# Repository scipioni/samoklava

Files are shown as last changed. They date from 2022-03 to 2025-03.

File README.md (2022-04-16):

# samoklava
## An autogenerated split 36 key keyboard

left | right
-|-
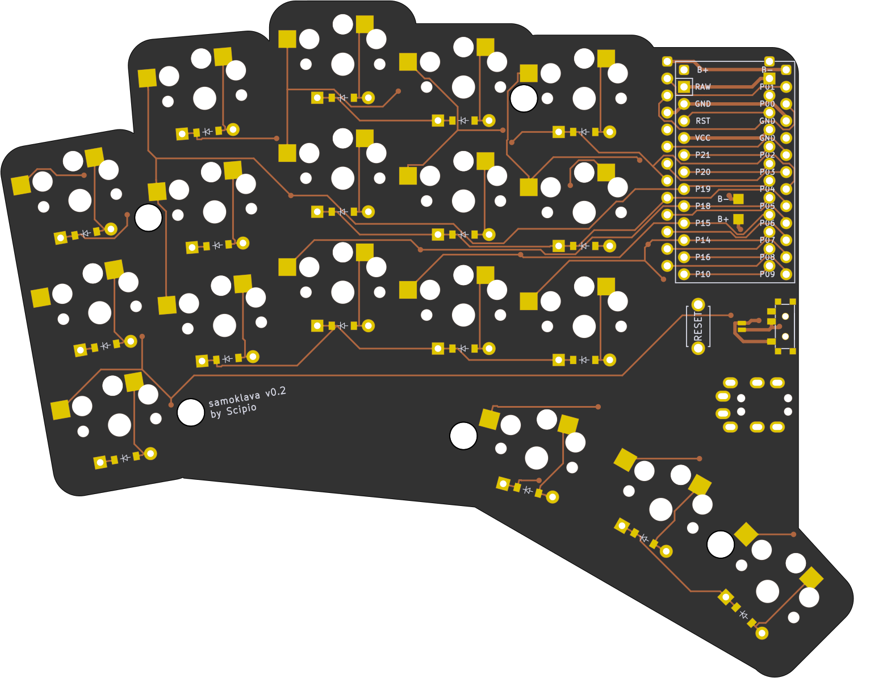
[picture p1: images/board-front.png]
left
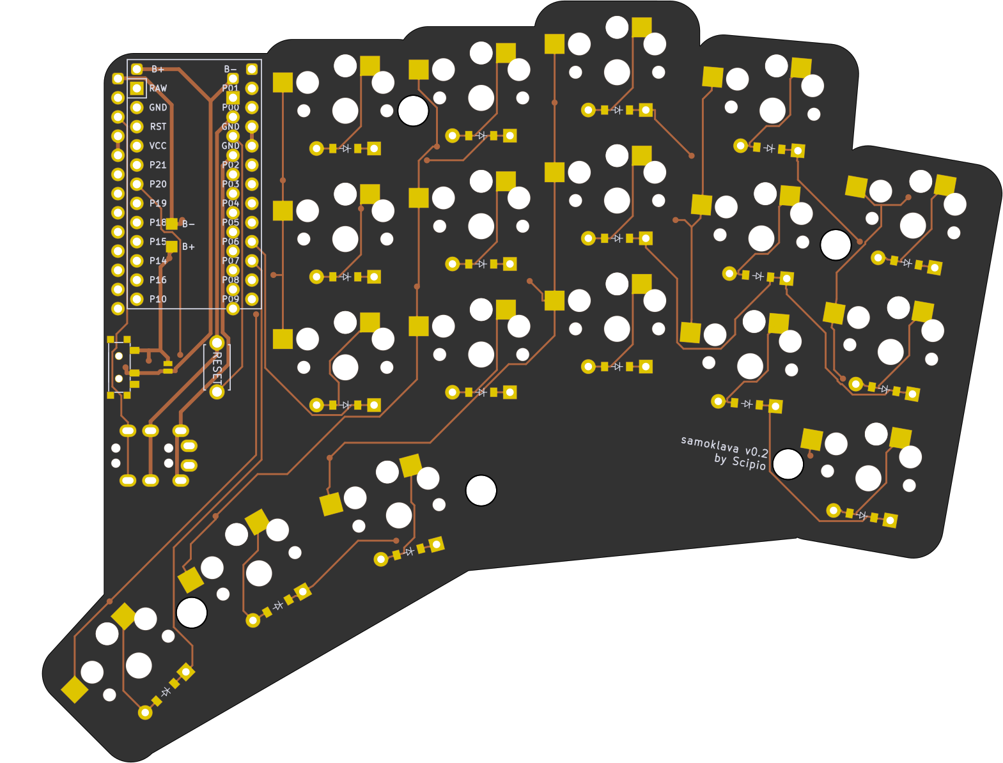
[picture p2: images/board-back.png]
right
 | 

A 5x3 split keyboard with 3 thumbs. There is nothing unique about the keyboard layout. It's inspired by Corne and Kyria, and
has the exact number of keys needed for the [Miryoku](https://github.com/manna-harbour/miryoku) layout.

The interesting thing about this keyboard is that it's a declarative design ("samoklava" can be loosely translated as
"keyboard that assembles itself" from Russian).
* Layout is declared using [Ergogen](https://github.com/mrzealot/ergogen/)
* The build system uses Ergogen to translate YAML to a KiCad PCB and plate files for FR-4 fab or laser cutting
* uses [kicad-automation-scripts](https://github.com/productize/kicad-automation-scripts) and [FreeRouting](https://github.com/freerouting/freerouting) to **automatically route the traces on the PCB**
* uses [KiKit](https://github.com/yaqwsx/KiKit) to render PCB previews (see top of this file) and production-ready **Gerber files**

## Features

* Extra pins and a slider switch for battery for wireless Promicro clones (tested with nice!nano); the slider can be
  shorted with a jumper if `CONFIG_ZMK_SLEEP` is preferred.
* Wired operation with QMK should be possible but is not tested; TRRS footprints are included and routed. The pinout is
  identical with a five-column Corne sans the RGBLEDs.
* Reset switches are easily accessible. The footprints used are the same as on the Corne.

## How to

  * make sure to have Docker CLI and NodeJS installed
  * run `make setup clean all`
  * check the `output` folder for KiCad PCBs and Gerbers
  * optional: create png render with `make png` and check output/routed_pcbs/board-front.png

See the [workflow](.github/workflows/build.yml) or the [Makefile](Makefile) for more details.

## Test layout

* https://ergogen.cache.works/

Upload samoklava.json except pcbs section. I print on paper with dxf format on qcad and:
* edit sheet properties -> printer offset -60,-60  

## Convert output dxf to svg

```
https://convertio.co/
```

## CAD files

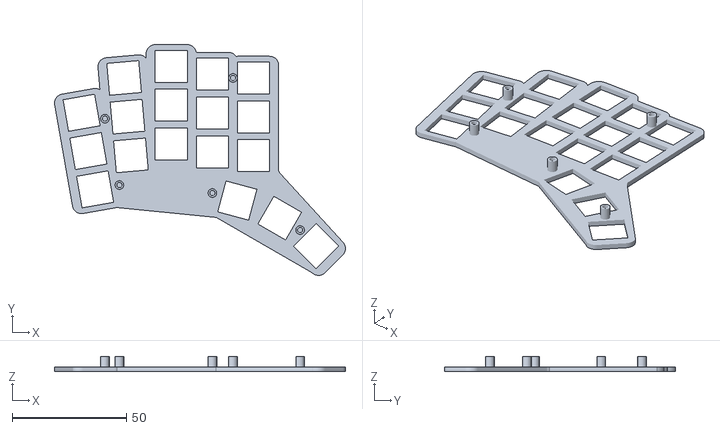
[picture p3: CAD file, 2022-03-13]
3d/samoklava.stl
127.3 x 100.9 x 6.55

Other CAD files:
3d/samoklava.blend

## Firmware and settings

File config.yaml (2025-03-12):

meta:
  engine: 4.0.4
  name: samoklava
  version: 0.3
  author: soundmonster
  url: https://github.com/soundmonster/samoklava
units:
  kx: cx
  ky: cy
  px: 2
  py: 2
points:
  key:
    footprints:
      choc_hotswap:
        type: choc
        params:
          hotswap: true
          reverse: true
          keycaps: true
        nets:
          from: =colrow
          to: =column_net
      diode:
        type: diode
        nets:
          from: =colrow
          to: =row_net
        anchor:
          shift: [0, -5]
  zones:
    matrix:
      key.padding: ky
      columns:
        pinky:
          key:
            stagger: 0 ky
            spread: kx
            column_net: col_pinky
        ring:
          key:
            stagger: 0.7 ky
            spread: kx
            column_net: col_ring
        middle:
          key:
            stagger: 0.2 ky
            spread: kx
            column_net: col_middle
        index:
          key:
            stagger: -0.2 ky
            spread: kx
            column_net: col_index
        inner:
          key:
            stagger: -0.1 ky
            spread: kx
            column_net: col_inner
      rows:
        bottom:
          row_net: row_bottom
        home:
          row_net: row_home
        top:
          row_net: row_top
    thumbfan:
      anchor:
        ref: matrix_inner_bottom
        shift: [-0.5 kx, -1 ky]
      columns:
        near:
          key:
            spread: kx
            splay: -15
            origin: [-0.5 kx, -0.5 ky]
            column_net: col_middle
        home:
          key:
            spread: kx
            splay: -15
            origin: [-0.5 kx, -0.5 ky]
            column_net: col_index
        far:
          key:
            spread: kx
            splay: -15
            origin: [-0.5 kx, -0.5 ky]
            column_net: col_inner
      rows:
        thumb:
          row_net: row_thumb
outlines:
  # board dimensions according to JLCPCB: 122.28 mm x 101.05 mm
  raw:
    - what: rectangle
      where: true
      asym: source
      size: [kx + px, ky + py]
      corner: px
  thumbfan_glue:
    - what: polygon
      points:
        - ref: matrix_inner_bottom
          shift: [0.5 kx + 0.5px, -0.5 ky + 0.5 py]
        - ref: thumbfan_far_thumb
          shift: [0.5 kx - 0.5px, 0.5 ky + 0.5 py]
        - ref: thumbfan_far_thumb
          shift: [0.5 kx - 0.5px, -0.5 ky - 0.5 py]
        - ref: thumbfan_near_thumb
          shift: [-0.5 kx + 0.5 px, -0.5 ky - 0.5 py]
        - ref: matrix_pinky_bottom
          shift: [0.5 kx - 0.5 py, -0.5 ky - 0.5 py]
        - ref: matrix_pinky_home
        - ref: matrix_inner_home
  patch_outer:
    - what: polygon
      points:
        - ref: matrix_ring_top
        - ref: matrix_ring_bottom
        - ref: matrix_pinky_bottom
          shift: [-0.5 (kx + px), 0]
        - ref: matrix_pinky_top
          shift: [-0.5 (kx + px), 0]
  patch_inner:
    - what: polygon
      points:
        - ref: matrix_inner_top
          shift: [0.5 (kx + px), 0]
        - ref: matrix_inner_bottom
          shift: [0.5 (kx + px), 0]
        - ref: matrix_index_bottom
        - ref: matrix_index_top
  controller_area:
    - what: rectangle
      where:
        - ref: matrix_inner_top
          # re-tranalte to new anchor position
          shift: [32/2 + 0 kx, 76.5/2 - 4.05 ky]
      size: [32, 76.5]
      corner: px
  switches:
    - what: rectangle
      where: true
      asym: source
      size: 14
  keycaps:
    - what: rectangle 
      where: true
      asym: source
      size: [kx, ky] 
      corner: 1
  keywell:
    - "raw"
    - "+patch_inner"
    - "+patch_outer"
    - "+thumbfan_glue"
  base_outline:
    - "keywell"
    - "+controller_area"
  screw_holes:
    top_left:
      what: circle
      where:
        - ref: matrix_ring_home
          shift: [-0.5 kx, 0 ky]
      radius: 1.05
    bottom_left:
      what: circle
      where:
        - ref: matrix_pinky_bottom
          shift: [0.5 kx, 0]
      radius: 1.05
    top_right:
      what: circle
      where:
        - ref: matrix_inner_top
          shift: [-0.5 kx, 0]
      radius: 1.05
    palm:
      what: circle
      where:
        - ref: matrix_index_bottom
          shift: [0, -1.06 ky]
      radius: 1.05
    thumb:
      what: circle
      where:
        - ref: thumbfan_far_thumb
          shift: [-0.55 kx, 0]
      radius: 1.05
  mounting_holes:
    $extends: outlines.screw_holes
    top_left:
      radius: 2.05
    bottom_left:
      radius: 2.05
    top_right:
      radius: 2.05
    palm:
      radius: 2.05
    thumb:
      radius: 2.05
  bottom_outline:
    - "base_outline"
    # TODO use footprints with pad + via reinforcement as mounting holes
    - "-screw_holes"
  plate:
    - "keywell"
    - "-switches"
    - "-screw_holes"
  pcb:
    - "base_outline"
    # TODO use footprints with pad + via reinforcement as mounting holes
    - "-mounting_holes"
pcbs:
  top_plate:
    outlines:
      edge:
        outline: plate
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

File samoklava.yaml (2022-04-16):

units:
  kx: cx
  ky: cy
  px: 4
  py: 2
points:
  key:
    footprints:
      choc_hotswap:
        type: choc
        params:
          hotswap: true
          reverse: true
          keycaps: true
        nets:
          # from: P1
          # to: P2
          from: =colrow
          to: =column_net
      diode:
        type: diode
        nets:
          # from: P3
          # to: P4
          from: =colrow
          to: =row_net
        anchor:
          shift: [0, -5]
  zones:
    matrix:
      # anchor:
      #   rotate: 5
      key.padding: 1 ky 
      columns:
        pinky:
          stagger: 0 ky
          spread: kx
          rotate: 12
          key:
            column_net: P20
        ring:
          stagger: 0.7 ky
          spread: kx
          rotate: -7
          key:
            column_net: P19
        middle:
          stagger: 0.2 ky
          spread: kx
          rotate: -5
          key:
            column_net: P18
        index:
          stagger: -0.2 ky
          spread: kx
          rotate: -0
          key:
            column_net: P15
        inner:
          stagger: -0.1 ky
          spread: kx
          key:
            column_net: P14
      rows:
        bottom:
          row_net: P6
        home:
          row_net: P5
        top:
          row_net: P4
    thumbfan:
      anchor:
        ref: matrix_inner_bottom
        shift: [-1.5 kx, -1.0 ky]
      columns:
        near:
          spread: kx
          rotate: -15
          origin: [-0.5 kx, -0.5 ky]
          key:
            column_net: P18
        home:
          spread: kx
          rotate: -15
          origin: [-0.5 kx, -0.5 ky]
          key:
            column_net: P15
        far:
          spread: kx
          rotate: -15
          origin: [-0.5 kx, -0.5 ky]
          key:
            column_net: P14
      rows:
        thumb:
          row_net: P7
outlines:
  # board dimensions according to JLCPCB: 122.28 mm x 101.05 mm
  exports:
    raw:
      - type: keys
        side: left
        size: [kx + px, ky + py]
        corner: px
    thumbfan_glue:
      - type: polygon
        points:
          - ref: matrix_inner_bottom
            shift: [0.5 kx + 0.6px, -0.5 ky + 0.5 py]
          - ref: thumbfan_far_thumb
            shift: [0.5 kx - 0.5px, 0.5 ky + 0.5 py]
          - ref: thumbfan_far_thumb
            shift: [0.5 kx - 0.5px, -0.5 ky - 0.5 py]
          - ref: thumbfan_near_thumb
            shift: [-0.5 kx + 0.5 px, -0.5 ky - 0.5 py]
          - ref: matrix_pinky_bottom
            shift: [0.5 kx - 0.5 py, -0.5 ky - 0.5 py]
          - ref: matrix_pinky_home
          - ref: matrix_inner_home
    patch_outer:
      - type: polygon
        points:
          - ref: matrix_ring_top
          - ref: matrix_ring_bottom
          - ref: matrix_pinky_bottom
            shift: [-0.5 (kx + px), 0]
          - ref: matrix_pinky_top
            shift: [-0.5 (kx + px), 0]
    patch_inner:
      - type: polygon
        points:
          - ref: matrix_inner_top
            shift: [0.5 (kx + px), 0]
          - ref: matrix_inner_bottom
            shift: [0.5 (kx + px), 0]
          - ref: matrix_index_bottom
          - ref: matrix_index_top
    controller_area:
      main:
        type: rectangle
        anchor:
          ref:
            - matrix_inner_top
          shift: [0 kx, -4.05 ky]
        size: [32, 76.5]
        corner: px
    switches:
      main:
        type: keys
        side: left
        size: 14
        bound: false
    keycaps:
      main:
        type: keys
        side: left
        size: [kx, ky]
        bound: false
        corner: 1
    keywell:
      main:
        type: outline
        name: raw
      patch_inner:
        type: outline
        name: patch_inner
        operation: add
      patch_outer:
        type: outline
        name: patch_outer
        operation: add
      thumbfan_glue:
        type: outline
        name: thumbfan_glue
        operation: add
    base_outline:
      main:
        type: outline
        name: keywell
      controller:
        type: outline
        name: controller_area
        operation: add
    screw_holes:
      top_left:
        type: circle
        anchor:
          - ref: matrix_ring_home
            shift: [-0.55 kx, 0 ky]
        radius: 0.80
      bottom_left:
        type: circle
        anchor:
          - ref: matrix_pinky_bottom
            shift: [0.6 kx, 0]
        radius: 0.80
      top_right:
        type: circle
        anchor:
          - ref: matrix_inner_top
            shift: [-0.5 kx, 0]
        radius: 0.80
      palm:
        type: circle
        anchor:
          - ref: matrix_index_bottom
            shift: [0, -1.06 ky]
        radius: 0.80
      thumb:
        type: circle
        anchor:
          - ref: thumbfan_far_thumb
            shift: [-0.55 kx, 0]
        radius: 0.80
    mounting_holes:
      $extends: outlines.exports.screw_holes
      top_left:
        radius: 2.05
      bottom_left:
        radius: 2.05
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

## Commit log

2022-02-23 Revert "thumbfan area"
    This reverts commit 8abc5109bb16d069a7e3d755b6a96e2d3aaa5510.
    [samoklava.yaml]
2022-03-13 blender plate
    [samoklava.blend, samoklava.stl]
